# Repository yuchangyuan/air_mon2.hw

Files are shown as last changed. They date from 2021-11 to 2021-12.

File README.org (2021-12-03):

#+title: A simple air monitor with multiple sensor

+ data collect with nodemcu-32s
+ WZ-H3/WZ-H3-K for HCOH
+ SGP30 for CO2 & TVOC
+ SHT3X for humidity compensations
+ PMS7003 for PM2.5

current version is v1.1, all sensor works:

+ only test with WZ-H3(manully soldering 2.54mm pin)
+ distance between SHT3X & ESP32 module is too small, cause measured temperature much higher than actual ambient temperature.

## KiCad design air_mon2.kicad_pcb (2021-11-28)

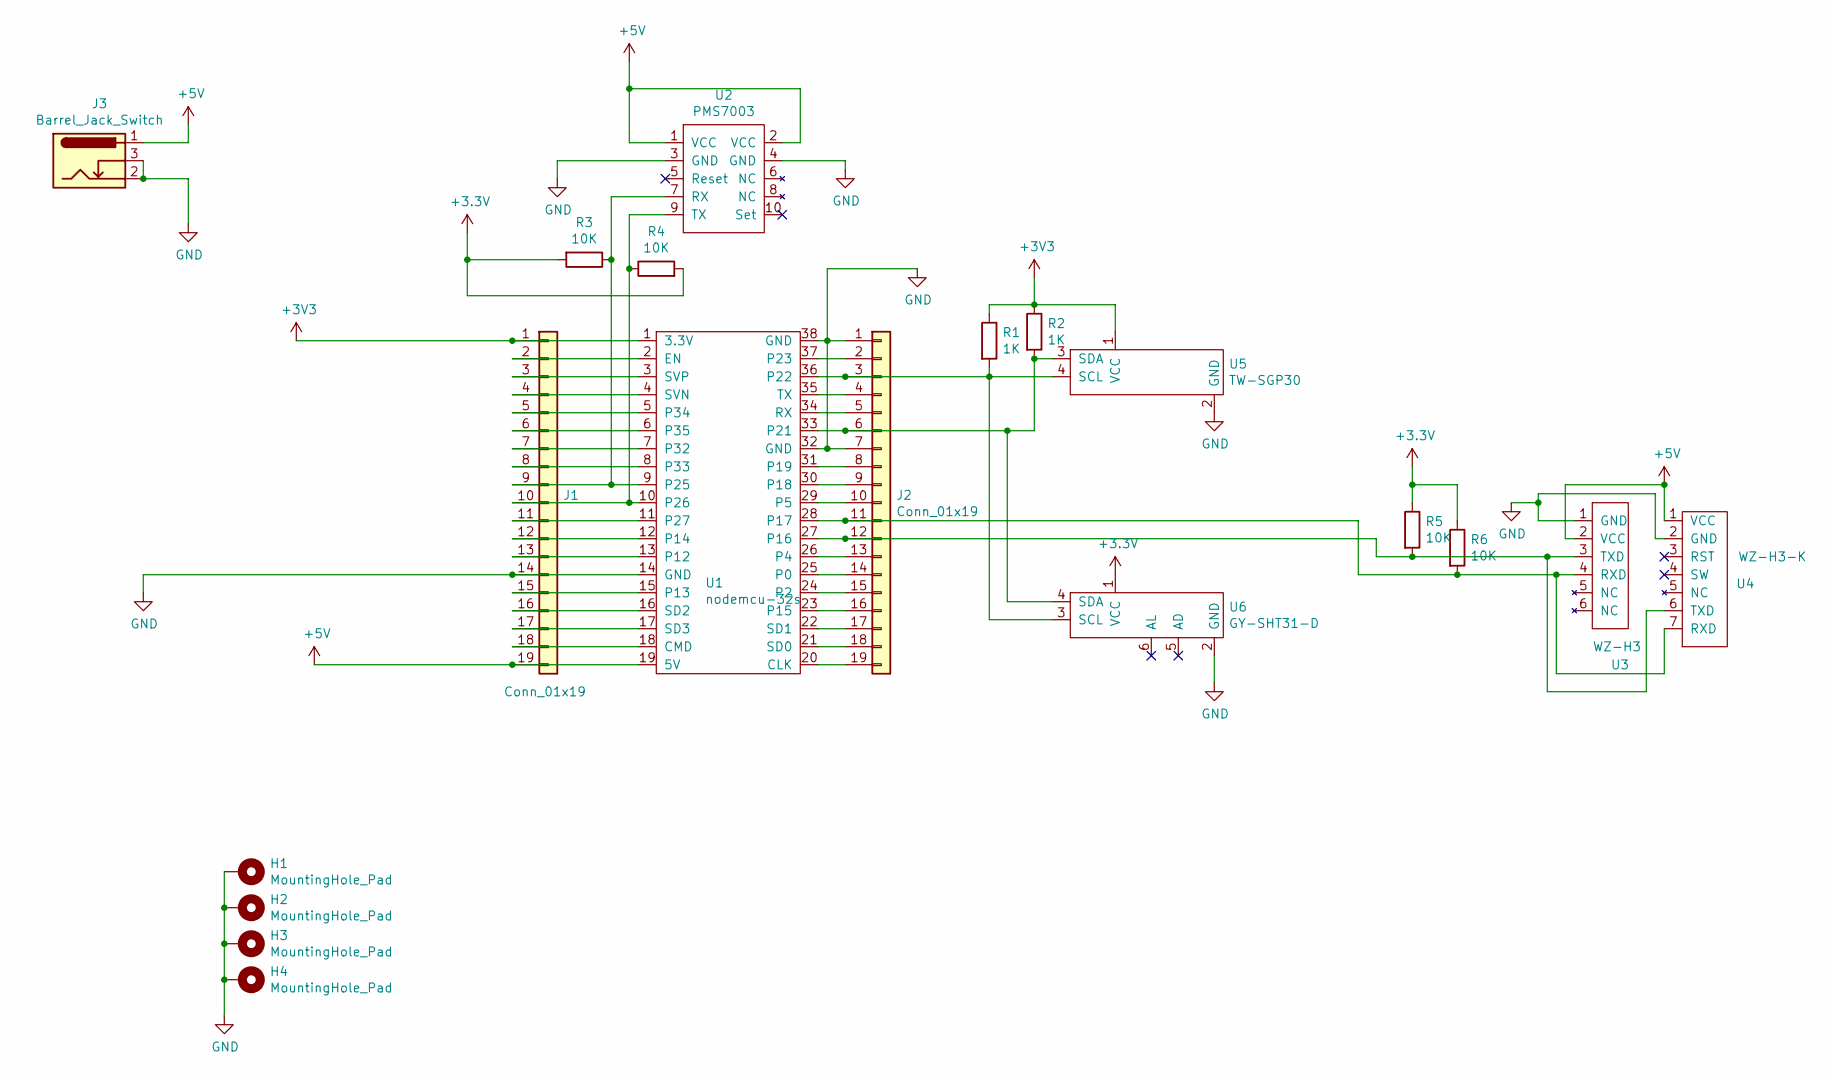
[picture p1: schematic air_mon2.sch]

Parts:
H1, H2, H3, H4: MountingHole_Pad; MountingHole_2.2mm_M2_Pad
J1, J2: Conn_01x19; PinHeader_1x19_P2.54mm_Vertical
J3: Barrel_Jack_Switch; BarrelJack_Horizontal
R1, R2: 1K; R_0805_2012Metric_Pad1.20x1.40mm_HandSolder
R3, R4, R5, R6: 10K; R_0805_2012Metric_Pad1.20x1.40mm_HandSolder
U1: nodemcu-32s
U2: PMS7003
U3: WZ-H3
U4: WZ-H3-K
U5: TW-SGP30
U6: GY-SHT31-D

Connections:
+5V: J1.19, J3.1, U1.19 (5V), U2.1 (VCC), U2.2 (VCC), U3.2 (VCC), U4.1 (VCC)
GND: H1.1, H2.1, H3.1, H4.1, J1.14, J2.1, J2.7, J3.2, J3.3, U1.14 (GND), U1.32 (GND), U1.38 (GND), U2.3 (GND), U2.4 (GND), U3.1 (GND), U4.2 (GND), U5.2 (GND), U6.2 (GND)
unnamed: J1.2, U1.2 (EN)
unnamed: J1.3, U1.3 (SVP)
unnamed: J1.4, U1.4 (SVN)
unnamed: J1.5, U1.5 (P34)
unnamed: J1.6, U1.6 (P35)
unnamed: J1.7, U1.7 (P32)
unnamed: J1.8, U1.8 (P33)
unnamed: J1.9, R3.1, U1.9 (P25), U2.7 (RX)
unnamed: J1.10, R4.1, U1.10 (P26), U2.9 (TX)
unnamed: J1.11, U1.11 (P27)
unnamed: J1.12, U1.12 (P14)
unnamed: J1.13, U1.13 (P12)
unnamed: J1.15, U1.15 (P13)
unnamed: J1.16, U1.16 (SD2)
unnamed: J1.17, U1.17 (SD3)
unnamed: J1.18, U1.18 (CMD)
unnamed: J2.2, U1.37 (P23)
unnamed: J2.3, R1.2, U1.36 (P22), U5.4 (SCL), U6.3 (SCL)
unnamed: J2.4, U1.35 (TX)
unnamed: J2.5, U1.34 (RX)
unnamed: J2.6, R2.2, U1.33 (P21), U5.3 (SDA), U6.4 (SDA)
unnamed: J2.8, U1.31 (P19)
unnamed: J2.9, U1.30 (P18)
unnamed: J2.10, U1.29 (P5)
unnamed: J2.11, R6.2, U1.28 (P17), U3.4 (RXD), U4.7 (RXD)
unnamed: J2.12, R5.2, U1.27 (P16), U3.3 (TXD), U4.6 (TXD)
unnamed: J2.13, U1.26 (P4)
unnamed: J2.14, U1.25 (P0)
unnamed: J2.15, U1.24 (P2)
unnamed: J2.16, U1.23 (P15)
unnamed: J2.17, U1.22 (SD1)
unnamed: J2.18, U1.21 (SD0)
unnamed: J2.19, U1.20 (CLK)

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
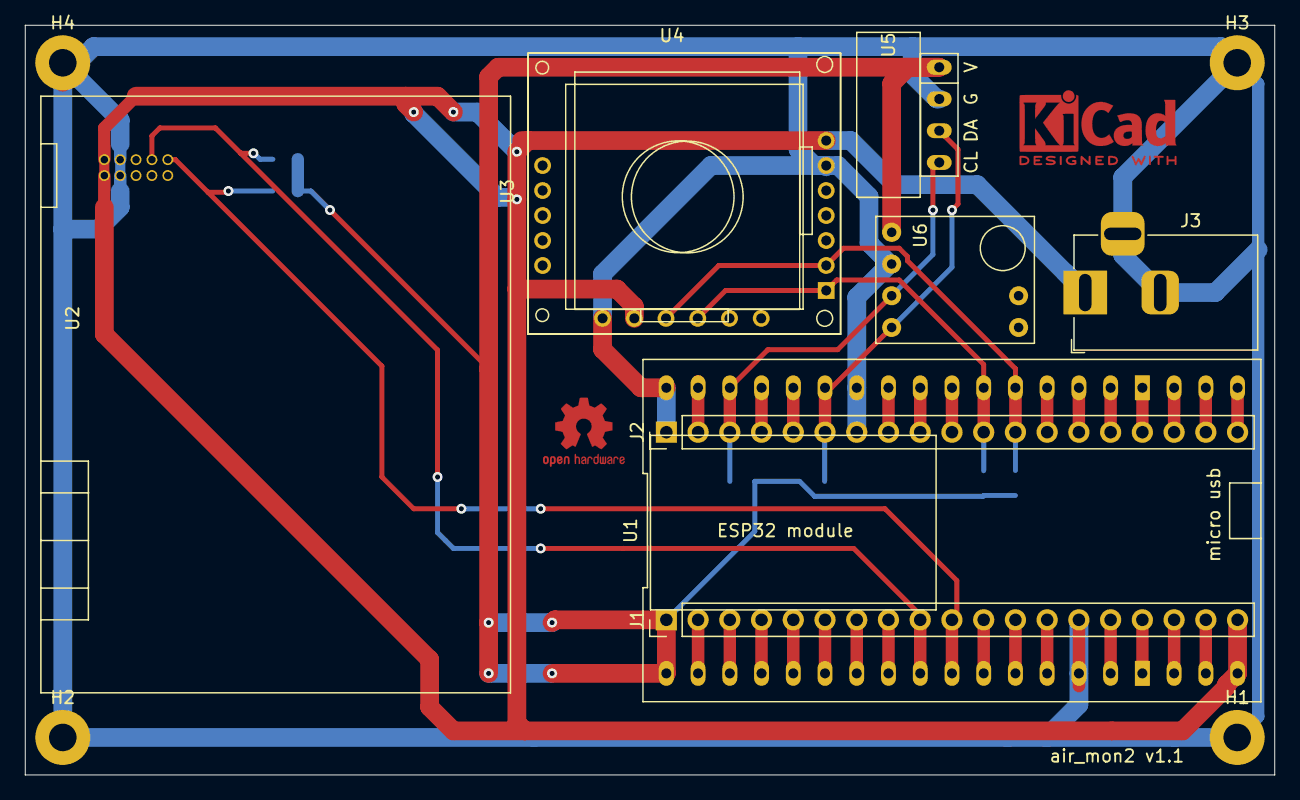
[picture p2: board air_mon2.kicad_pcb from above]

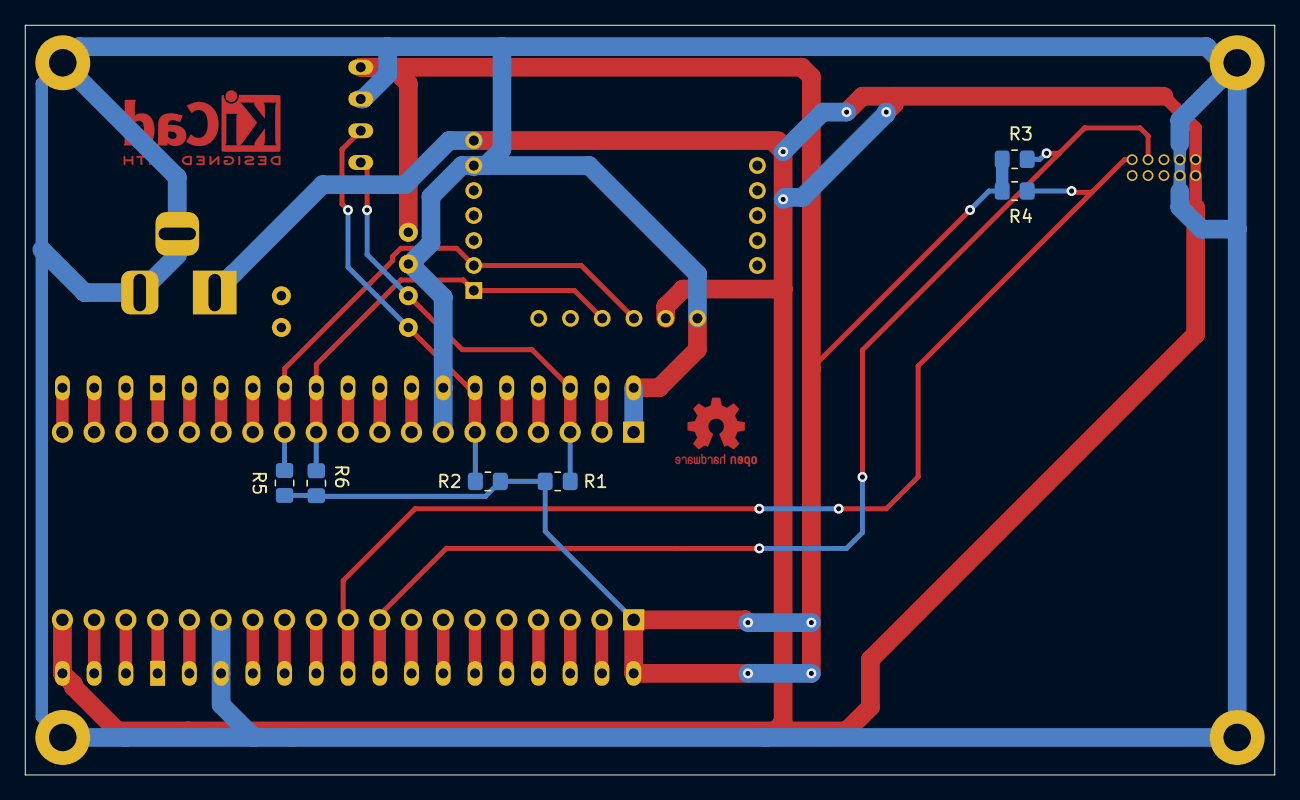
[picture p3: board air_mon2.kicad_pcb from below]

Board: 2 copper layers, 100.0 x 60.0 mm, 19 parts (6 on the bottom side), 36 nets.

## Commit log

2021-11-28 v1, has problem
    1. wz-h3 2.54 pin has wrong direction
    2. all txd & rxd need pull up
    3. sgp30 module has no enough distance from dc power jack
    4. need add sth3x sensor
    [air_mon2-B_Cu.gbl, air_mon2-B_Mask.gbs, air_mon2-B_Paste.gbp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]
2021-11-28 update, v1.1
    1. add sth31
    2. fix wz-h3
    [air_mon2-B_Cu.gbl, air_mon2-B_Mask.gbs, air_mon2-B_Paste.gbp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]
2021-11-28 remove alignment
    [air_mon2-B_Cu.gbl, air_mon2-B_Mask.gbs, air_mon2-B_Paste.gbp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]
